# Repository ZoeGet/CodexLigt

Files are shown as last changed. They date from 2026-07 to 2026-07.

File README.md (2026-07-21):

# CodexLight

[English](README.en.md) | 简体中文 | [使用说明](USAGE.md) | [English Usage Guide](USAGE.en.md)

CodexLight 是一套基于 ESP32-C3 的 Codex Desktop 状态灯。Windows 端 Bridge 读取本机 Codex 会话日志，把状态转换为 `GREEN`、`RED`、`YELLOW`，再通过 USB 串口、局域网 UDP 或两者同时发送给 ESP32-C3。固件驱动三颗独立 WS2812B LED 显示空闲、工作和等待状态。

本项目是社区开源项目，与 OpenAI 没有官方关联或背书。

## 当前可用方案

- 配网使用 USB 串口，不再使用 ESP32 AP 热点页面。
- 托盘程序提供 `Configure WiFi`，通过 USB 把 SSID 和密码发送给设备。
- Wi-Fi 只在连接成功后写入 ESP32 NVS；错误密码不会覆盖旧配置。
- 已保存的 Wi-Fi 会在开机后非阻塞连接，并在断线后持续重试。
- ESP32-C3 Wi-Fi 发射功率默认限制为 8.5 dBm，以提升部分开发板的无线连接稳定性。
- 无电脑供电启动不依赖 USB 串口，适合充电宝或电池供电的纯无线摆放。
- 支持 `AUTO`、`WIRED`、`WIRELESS` 三种持久化通信模式。
- `Bridge/start_codex_light_tray.vbs` 默认以无线模式隐藏启动，不保留 PowerShell 窗口。

## 状态定义

| 状态 | Codex 条件 | LED | GPIO |
| --- | --- | --- | --- |
| `GREEN` | 空闲、任务完成或任务中止 | 绿灯 | GPIO6 |
| `RED` | 正在思考、回复、运行工具或处理任务 | 红灯 | GPIO7 |
| `YELLOW` | 等待审批、权限确认或用户输入 | 黄灯 | GPIO5 |
| 未收到电脑心跳 | 6 秒内没有有效 USB/UDP 心跳 | 黄灯慢闪 | GPIO5 |

首次收到有效电脑心跳时，绿灯会闪烁 2 秒作为连接提示，然后显示真实状态。任务完成后的绿色会保持到下一次任务开始、进入等待状态或连接断开。

## 快速开始

1. 安装电脑端依赖：

   ```powershell
   python -m pip install pyserial
   ```

2. 编译并烧录固件：

   ```powershell
   cd Firmware
   pio run
   pio run -t upload --upload-port COM4
   ```

3. 双击启动隐藏托盘，默认进入无线模式：

   ```text
   Bridge\start_codex_light_tray.vbs
   ```

4. 第一次使用时，用 USB 连接 ESP32-C3，右键托盘图标选择 `Configure WiFi`，输入路由器 SSID 和密码。
5. Wi-Fi 保存成功后，可以拔掉电脑 USB，改用充电宝或锂电池供电；托盘会通过 UDP 控灯。

完整流程见 [USAGE.md](USAGE.md)。

## 纯无线使用

1. 先用 USB 完成一次 `Configure WiFi`。
2. 确认托盘模式是 `Wireless only`，或用默认 `start_codex_light_tray.vbs` 启动。
3. 断开电脑 USB，使用充电宝或稳定 5 V 电源给 ESP32-C3 和 LED 供电。
4. 打开托盘后，日志应出现：

   ```text
   SERIAL no matching serial port
   SERIAL setup skipped; using saved firmware mode.
   UDP ack from 192.168.x.x CODEXLIGHT/1 ACK ... active=WIRELESS state=...
   ```

这表示设备未接电脑串口，但已通过 Wi-Fi UDP 正常工作。

## 无串口诊断灯码

| 灯码 | 含义 |
| --- | --- |
| 红黄交替 | 没有读到 Wi-Fi 配置，需要 USB 配网 |
| 红色双闪循环 | 有 Wi-Fi 配置，但正在重连或连接失败 |
| 黄灯慢闪 | Wi-Fi 已连接，正在等待电脑托盘 UDP 心跳 |
| 正常红/绿/黄 | 已收到电脑状态，系统正常工作 |

## 硬件

推荐器件：

- ESP32-C3 SuperMini 或兼容 ESP32-C3 开发板
- 三颗 WS2812B RGB LED
- 稳定 5 V 电源、充电宝或合适的锂电池升压模块
- USB 数据线，用于烧录和第一次 Wi-Fi 配网

接线：

| 功能 | ESP32-C3 引脚 |
| --- | --- |
| 黄灯 DIN | GPIO5 |
| 绿灯 DIN | GPIO6 |
| 红灯 DIN | GPIO7 |
| WS2812B VCC | 5 V |
| WS2812B GND | GND |

三颗 WS2812B 使用三路独立数据输入，不是串联灯带。当前固件使用 `NEO_GRB + NEO_KHZ800`，默认亮度为 `DEFAULT_BRIGHTNESS = 50`，可在 [Firmware/include/config.h](Firmware/include/config.h) 中配置。

## 目录结构

```text
CodexLight/
├── Bridge/        # Windows 日志监听、串口/UDP 发送和托盘程序
├── Firmware/      # ESP32-C3 PlatformIO 固件
├── Hardware/      # BOM、原理图、PCB、Gerber、外壳 STL
├── Docs/          # 使用与实现说明
├── README.md      # 中文项目说明
├── README.en.md   # English project documentation
├── USAGE.md       # 中文使用手册
└── USAGE.en.md    # English usage guide
```

## 验证

```powershell
python -B -m py_compile Bridge\codex_light_monitor.py
powershell -NoProfile -Command "$e=$null; [System.Management.Automation.PSParser]::Tokenize((Get-Content -LiteralPath 'Bridge\CodexLightTray.ps1' -Raw), [ref]$e) | Out-Null; if($e){$e; exit 1}else{'OK'}"
cd Firmware
pio run
```

## 许可

本项目使用 [MIT License](LICENSE)。第三方依赖遵循各自许可。

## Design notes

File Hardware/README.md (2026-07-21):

# CodexLight Hardware

[项目主页](../README.md) | [Project Home](../README.en.md)

本目录包含 CodexLight 的 BOM、原理图、PCB 制造资料和 3D 打印外壳。

This directory contains the CodexLight bill of materials, schematic, PCB manufacturing files, and 3D-printable enclosure.

## Files / 文件

| Path | Description |
| --- | --- |
| `BOM/BOM.xlsx` | 物料清单 / Bill of materials |
| `Schematic/Schematic1.pdf` | 原理图 PDF / Schematic PDF |
| `PCB/Source/CodexLight.epro2` | PCB 源工程 / PCB source project |
| `PCB/Gerber/CodexLight_PCB_Gerber.zip` | Gerber 制造包 / Gerber fabrication package |
| `Enclosure/CodexLight_T.stl` | 上壳 / Top enclosure |
| `Enclosure/CodexLight_B.stl` | 下壳 / Bottom enclosure |

## LED Connections / LED 连接

| LED | GPIO |
| --- | --- |
| Yellow WS2812B DIN / 黄灯 DIN | GPIO5 |
| Green WS2812B DIN / 绿灯 DIN | GPIO6 |
| Red WS2812B DIN / 红灯 DIN | GPIO7 |

三颗 LED 使用独立数据线，不是串联灯带。LED 电源和 ESP32-C3 必须共地，并使用稳定 5 V 供电。

The three LEDs use independent data lines, not a chained strip. The LED supply and ESP32-C3 must share ground, and a stable 5 V supply is required.

## Standalone Power / 独立供电

纯无线使用时，ESP32-C3 和 WS2812B 都需要从充电宝、5 V 稳压模块或锂电池升压模块供电。不要只给 LED 供电；ESP32-C3 的 `5V/VIN` 和 GND 也必须接入同一电源系统。

For wireless-only use, both the ESP32-C3 and WS2812B LEDs must be powered from the power bank, 5 V regulator, or Li-ion boost converter. Do not power only the LEDs. The ESP32-C3 `5V/VIN` and GND must be connected to the same supply system.

## Notes / 注意

- 固件默认使用 `NEO_GRB + NEO_KHZ800`。
- 如果更换不同批次 WS2812B 后颜色不对，请检查色序、DIN 方向、焊接和供电。
- USB 数据线仍然建议保留，因为固件烧录和首次 Wi-Fi 配网依赖 USB 串口。
- ESP32-C3 连接 Wi-Fi 时会有电流尖峰；如果使用小型升压模块，确认动态电压不会跌落。

- Firmware defaults to `NEO_GRB + NEO_KHZ800`.
- If another WS2812B batch displays incorrect colors, verify pixel order, DIN orientation, soldering, and power.
- Keep USB data access available because firmware upload and first-time Wi-Fi provisioning use USB serial.
- ESP32-C3 current spikes during Wi-Fi association. If using a small boost converter, verify dynamic voltage does not sag.

## License

Unless a third-party component states otherwise, hardware files follow the repository [MIT License](../LICENSE).

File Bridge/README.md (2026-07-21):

# CodexLight Bridge

[English](README_en.md) | 简体中文 | [项目主页](../README.md)

Bridge 运行在 Windows 电脑上，读取本机 Codex Desktop 会话日志，把状态映射为 `GREEN`、`RED`、`YELLOW`，再通过 USB 串口、局域网 UDP 或两者同时发送给 ESP32-C3。

## 功能

- 监听 `~/.codex/sessions/**/*.jsonl` 和 `~/.codex/logs_2.sqlite`。
- 支持 USB 串口、UDP、AUTO 混合模式。
- 提供 Windows 托盘菜单：配网、切换模式、查看日志、重启监控、退出。
- 通过 USB 串口为设备配置 Wi-Fi，不使用 ESP32 AP 热点。
- 自动记住最近发现的 UDP 设备，方便下次启动继续使用无线连接。
- 无电脑 USB 时，托盘会跳过串口设置并继续用已保存的无线模式发送 UDP。

## 状态规则

| Codex 事件 | 输出 |
| --- | --- |
| `task_started`、推理、消息、工具调用和工具输出 | `RED` |
| 工具调用需要审批、权限或用户输入 | `YELLOW` |
| `task_complete` 或 `turn_aborted` | `GREEN` |

Bridge 只发送颜色状态，不发送 Codex 消息正文、工具输出、API Key 或登录令牌。

## 依赖

```powershell
python -m pip install pyserial
```

## 托盘启动

推荐双击隐藏启动器，默认进入 `WIRELESS` 模式：

```text
Bridge\start_codex_light_tray.vbs
```

旧批处理也可用，但可能短暂显示控制台窗口：

```text
Bridge\start_codex_light_tray.bat
```

托盘菜单：

- `Configure WiFi`：通过 USB 写入路由器 SSID/密码。
- `Connection mode`：切换 `Auto (wired + wireless)`、`Wired only`、`Wireless only`。
- `Open log folder`：打开 `Bridge/logs`。
- `Restart monitor`：重启监控进程。
- `Exit`：退出。

## Wi-Fi 配网

托盘 `Configure WiFi` 会暂停监控进程，打开串口，发送：

```text
WIFI_SET <ssid><TAB><password>
```

设备连接成功后返回：

```text
WIFI_SET_OK <ssid> <ip>
```

失败日志保存到：

```text
Bridge\logs\wifi_setup.out.log
Bridge\logs\wifi_setup.err.log
```

命令行配网：

```powershell
python Bridge\codex_light_monitor.py --serial auto --wifi-ssid "YourWifi" --wifi-password "YourPassword"
```

## 运行模式

| 模式 | Bridge 行为 |
| --- | --- |
| `WIRED` | 打开串口并只通过 USB 发送状态 |
| `WIRELESS` | 通过 UDP 发送状态；如果 USB 存在，会用串口保存 `MODE WIRELESS` 后释放；如果 USB 不存在，会直接使用设备已保存模式 |
| `AUTO` | 串口和 UDP 同时启用，固件优先使用新鲜串口心跳 |

手动运行：

```powershell
python Bridge\codex_light_monitor.py --serial auto --baud 115200
python Bridge\codex_light_monitor.py --udp --udp-port 4210
python Bridge\codex_light_monitor.py --serial auto --baud 115200 --udp --udp-port 4210 --firmware-mode AUTO
```

## 常用参数

| 参数 | 说明 |
| --- | --- |
| `--serial COM4` | 指定串口 |
| `--serial auto` | 自动选择常见 ESP32/USB 串口 |
| `--baud 115200` | 串口波特率 |
| `--udp` | 启用 UDP 状态发送和发现 |
| `--udp-port 4210` | UDP 端口 |
| `--firmware-mode AUTO` | 通过串口保存固件模式 |
| `--serial-setup-only` | 串口只用于模式设置，确认后释放 |
| `--reset-on-connect` | 打开串口后发送 ESP32 reset pulse，用于无线托盘启动时初始化设备 |
| `--wifi-ssid` / `--wifi-password` | 一次性 USB Wi-Fi 配网 |
| `--wifi-config path.json` | 从 JSON 文件读取 `{ "ssid": "...", "password": "..." }` |

## 日志

- `Bridge/logs/codex_light_monitor.out.log`
- `Bridge/logs/codex_light_monitor.err.log`
- `Bridge/logs/wifi_setup.out.log`
- `Bridge/logs/wifi_setup.err.log`

## 验证

```powershell
python -B -m py_compile Bridge\codex_light_monitor.py
powershell -NoProfile -Command "$e=$null; [System.Management.Automation.PSParser]::Tokenize((Get-Content -LiteralPath 'Bridge\CodexLightTray.ps1' -Raw), [ref]$e) | Out-Null; if($e){$e; exit 1}else{'OK'}"
```

## License

Bridge 遵循仓库根目录的 [MIT License](../LICENSE)。

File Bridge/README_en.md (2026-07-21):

# CodexLight Bridge

English | [简体中文](README.md) | [Project Home](../README.en.md)

The Bridge runs on the Windows computer hosting Codex Desktop. It reads local Codex session logs, maps activity to `GREEN`, `RED`, or `YELLOW`, and sends the state to the ESP32-C3 over USB serial, LAN UDP, or both.

## Features

- Monitors `~/.codex/sessions/**/*.jsonl` and `~/.codex/logs_2.sqlite`.
- Supports USB serial, UDP, and mixed AUTO mode.
- Provides a Windows tray menu for Wi-Fi setup, mode switching, logs, monitor restart, and exit.
- Configures device Wi-Fi over USB serial. The firmware no longer uses an ESP32 AP portal.
- Remembers the most recently discovered UDP device for wireless startup.
- When no computer USB is connected, the tray skips serial setup and continues UDP using the device's saved wireless mode.

## State Rules

| Codex event | Output |
| --- | --- |
| `task_started`, reasoning, messages, tool calls, and tool outputs | `RED` |
| A tool call requires approval, permission, or user input | `YELLOW` |
| `task_complete` or `turn_aborted` | `GREEN` |

The Bridge sends only color states. It never sends Codex message text, tool output, API keys, or login tokens to the device.

## Dependency

```powershell
python -m pip install pyserial
```

## Tray Startup

Recommended hidden launcher. It defaults to `WIRELESS` mode:

```text
Bridge\start_codex_light_tray.vbs
```

The legacy batch launcher is also available, but it may briefly show a console window:

```text
Bridge\start_codex_light_tray.bat
```

Tray menu:

- `Configure WiFi`: write router SSID/password over USB.
- `Connection mode`: switch between `Auto (wired + wireless)`, `Wired only`, and `Wireless only`.
- `Open log folder`: open `Bridge/logs`.
- `Restart monitor`: restart the monitor process.
- `Exit`: quit.

## Wi-Fi Provisioning

The tray `Configure WiFi` action pauses the monitor process, opens serial, and sends:

```text
WIFI_SET <ssid><TAB><password>
```

On success, the device replies:

```text
WIFI_SET_OK <ssid> <ip>
```

Failure logs are written to:

```text
Bridge\logs\wifi_setup.out.log
Bridge\logs\wifi_setup.err.log
```

Command-line provisioning:

```powershell
python Bridge\codex_light_monitor.py --serial auto --wifi-ssid "YourWifi" --wifi-password "YourPassword"
```

## Run Modes

| Mode | Bridge behavior |
| --- | --- |
| `WIRED` | Opens serial and sends states only over USB |
| `WIRELESS` | Sends states over UDP; if USB exists, serial saves `MODE WIRELESS` and is released; if USB is absent, the saved firmware mode is used |
| `AUTO` | Enables serial and UDP; firmware prefers a fresh serial heartbeat |

Manual commands:

```powershell
python Bridge\codex_light_monitor.py --serial auto --baud 115200
python Bridge\codex_light_monitor.py --udp --udp-port 4210
python Bridge\codex_light_monitor.py --serial auto --baud 115200 --udp --udp-port 4210 --firmware-mode AUTO
```

## Common Options

| Option | Description |
| --- | --- |
| `--serial COM4` | Use a specific serial port |
| `--serial auto` | Auto-select a common ESP32/USB serial device |
| `--baud 115200` | Serial baud rate |
| `--udp` | Enable UDP state output and discovery |
| `--udp-port 4210` | UDP port |
| `--firmware-mode AUTO` | Persist firmware mode over serial |
| `--serial-setup-only` | Use serial only for mode setup, then release it |
| `--reset-on-connect` | Pulse ESP32 reset lines after opening serial; used by wireless tray startup to initialize the device |
| `--wifi-ssid` / `--wifi-password` | One-shot USB Wi-Fi provisioning |
| `--wifi-config path.json` | Read `{ "ssid": "...", "password": "..." }` from JSON |

## Logs

- `Bridge/logs/codex_light_monitor.out.log`
- `Bridge/logs/codex_light_monitor.err.log`
- `Bridge/logs/wifi_setup.out.log`
- `Bridge/logs/wifi_setup.err.log`

## Verification

```powershell
python -B -m py_compile Bridge\codex_light_monitor.py
powershell -NoProfile -Command "$e=$null; [System.Management.Automation.PSParser]::Tokenize((Get-Content -LiteralPath 'Bridge\CodexLightTray.ps1' -Raw), [ref]$e) | Out-Null; if($e){$e; exit 1}else{'OK'}"
```

## License

The Bridge is covered by the repository's [MIT License](../LICENSE).

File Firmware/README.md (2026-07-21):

# CodexLight Firmware

[项目主页](../README.md) | [Project Home](../README.en.md)

本目录是 ESP32-C3 端 PlatformIO Arduino 固件。固件负责 USB Wi-Fi 配网、STA 联网、USB 串口/UDP 心跳接收、通信模式持久化、无串口启动诊断灯码和三路 WS2812B 状态显示。

This directory contains the ESP32-C3 PlatformIO Arduino firmware. It handles USB Wi-Fi provisioning, STA networking, USB serial/UDP heartbeats, persistent transport modes, standalone LED diagnostics, and three independent WS2812B status LEDs.

## Build Environment / 构建环境

```ini
platform = espressif32@6.6.0
board = esp32-c3-devkitm-1
framework = arduino
monitor_speed = 115200
```

PlatformIO installs the external dependency automatically:

- `Adafruit NeoPixel`

当前固件不再依赖 `WiFiManager`、`ESPAsyncWebServer` 或 AP 配网页面。

The current firmware no longer depends on `WiFiManager`, `ESPAsyncWebServer`, or an AP provisioning portal.

## Build and Upload / 编译与烧录

```powershell
cd Firmware
pio run
pio run -t upload --upload-port COM4
pio device monitor --port COM4 --baud 115200
```

普通串口监视器会占用 COM 口。使用 Bridge 或托盘前请关闭 PlatformIO Monitor。

Close PlatformIO Monitor before starting the Bridge or tray because only one process can use the COM port.

## Main Configuration / 主要配置

Edit `include/config.h`:

| Setting | Default | Description |
| --- | --- | --- |
| `YELLOW_LED_PIN` | `5` | Yellow LED data pin |
| `GREEN_LED_PIN` | `6` | Green LED data pin |
| `RED_LED_PIN` | `7` | Red LED data pin |
| `DEFAULT_BRIGHTNESS` | `50` | NeoPixel brightness |
| `SERIAL_BAUD` | `115200` | USB CDC baud rate |
| `UDP_PORT` | `4210` | UDP listen/discovery port |
| `LINK_TIMEOUT_MS` | `6000` | Desktop heartbeat timeout |
| `WIFI_CONNECT_TIMEOUT_MS` | `15000` | Blocking connect timeout used only during USB provisioning validation |
| `WIFI_RECONNECT_INTERVAL_MS` | `10000` | Non-blocking saved Wi-Fi retry interval |
| `WIFI_MAX_TX_POWER_QDBM` | `34` | ESP-IDF quarter-dBm units; 34 means 8.5 dBm |
| `DEFAULT_TRANSPORT_MODE` | `AUTO` | Default mode when NVS has none |
| `DEBUG_SERIAL` | `false` | Default debug logging; keep disabled for standalone wireless operation |

`CONFIG_AP_*` constants are retained only for compatibility. The main firmware does not start a SoftAP.

`CONFIG_AP_*` 常量仅保留兼容用途，主固件不会启动热点。

## Wi-Fi Provisioning / Wi-Fi 配网

Use USB serial:

```text
WIFI_SET <ssid><TAB><password>
```

During provisioning, the firmware validates the credentials by attempting STA connection. Credentials are saved in Preferences namespace `wifi` only after successful connection:

```text
ssid
password
```

配网失败不会覆盖旧配置。保存过 Wi-Fi 后，启动时使用非阻塞连接；如果连接失败，固件保留凭据并按 `WIFI_RECONNECT_INTERVAL_MS` 持续重试。

Failed provisioning does not overwrite existing credentials. Once Wi-Fi is saved, boot uses a non-blocking connect path. If the connection fails, credentials are kept and the firmware retries every `WIFI_RECONNECT_INTERVAL_MS`.

Clear Wi-Fi:

```text
CLEAR_WIFI
```

## Transport Modes / 通信模式

| Mode | Behavior |
| --- | --- |
| `WIRED` | Accept USB serial heartbeat only |
| `WIRELESS` | Accept UDP heartbeat only |
| `AUTO` | Accept both; fresh USB heartbeat has priority |

Commands:

```text
MODE WIRED
MODE WIRELESS
MODE AUTO
STATUS
```

The selected mode is saved in Preferences namespace `codexlight`, key `transport`.

## LED Runtime and Diagnostics / LED 运行与诊断

| Pattern | Meaning |
| --- | --- |
| Solid green | Idle, task complete, or task aborted |
| Solid red | Codex is working |
| Solid yellow | Waiting for approval, permission, or user input |
| Green blink for 2 seconds | First desktop heartbeat connected |
| Slow yellow blink | Wi-Fi is connected but no desktop heartbeat has arrived |
| Alternating red/yellow | No saved Wi-Fi credentials |
| Repeating red double-blink | Saved Wi-Fi exists but reconnect is in progress or failed |

独立供电时不要依赖串口输出判断状态，直接看灯码即可。

When running from a power bank or battery, use the LED diagnostics instead of serial output.

## Serial Commands / 串口命令

```text
GREEN
RED
YELLOW
PING
STATUS
MODE WIRED
MODE WIRELESS
MODE AUTO
WIFI_CONFIG
WIFI_SET <ssid><TAB><password>
CLEAR_WIFI
LED_TEST RED
LED_TEST GREEN
LED_TEST YELLOW
LED_TEST OFF
```

`WIFI_CONFIG` only prints the USB provisioning hint. It does not open an AP.

`WIFI_CONFIG` 只提示使用 USB 配网，不会打开热点。

## UDP Protocol / UDP 协议

Accepted packets:

```text
CODEXLIGHT/1 GREEN
CODEXLIGHT/1 RED
CODEXLIGHT/1 YELLOW
CODEXLIGHT/1 PING
```

Acknowledgement:

```text
CODEXLIGHT/1 ACK mac=<MAC> mode=<MODE> active=<TRANSPORT> state=<STATE>
```

Discovery:

```text
CODEXLIGHT/1 HELLO mac=<MAC> mode=<MODE>
```

## Files / 文件

- `src/main.cpp`: serial commands, UDP heartbeat, transport selection, LED state machine, diagnostics.
- `src/config_portal.cpp`: STA Wi-Fi, USB provisioning wrapper, non-blocking saved Wi-Fi reconnect.
- `src/storage.cpp`: Preferences read/write for Wi-Fi credentials.
- `src/led.cpp`: three independent Adafruit NeoPixel outputs.
- `include/config.h`: user-editable GPIO, timing, brightness, port, and Wi-Fi power settings.
- `platformio.ini`: PlatformIO environment and dependencies.

## NVS and Reset / NVS 与擦除

Wi-Fi credentials and transport mode are stored in NVS. Normal firmware upload does not erase them.

```powershell
pio run -t erase --upload-port COM4
pio run -t upload --upload-port COM4
```

Usually `CLEAR_WIFI` and `MODE ...` are enough. Full erase is only needed for factory reset or corrupted NVS.

## License

Firmware follows the repository [MIT License](../LICENSE). Third-party dependencies keep their own licenses.

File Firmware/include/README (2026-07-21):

# Firmware Headers

Project header files / 项目头文件：

- `config.h`: GPIO assignments, brightness, serial baud, UDP port, timeouts, default transport mode, standalone diagnostic behavior, and ESP32-C3 Wi-Fi transmit power.
- `config_portal.h`: STA Wi-Fi connection and USB provisioning wrapper. The name is kept for compatibility with older code; AP provisioning is no longer used.
- `storage.h`: Preferences storage for Wi-Fi SSID/password.
- `led.h`: three-channel LED controller interface.

用户通常只需要修改 `config.h`。修改后重新运行 `pio run` 并烧录。

Users normally edit `config.h` only. Rebuild and upload after changing it.

See `Firmware/README.md` and the repository root README for complete instructions.

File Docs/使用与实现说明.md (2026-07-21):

# CodexLight 使用与实现说明

[English](USAGE_AND_IMPLEMENTATION.md) | 简体中文 | [返回文档索引](README.md) | [项目主页](../README.md)

本文合并项目操作手册和技术实现说明，覆盖固件烧录、USB Wi-Fi 配网、有线/无线运行、排障和维护。

## 硬件连接

| LED | 数据引脚 | 状态 |
| --- | --- | --- |
| 黄色 WS2812B | GPIO5 | 未连接、等待或诊断 |
| 绿色 WS2812B | GPIO6 | 连接动画或任务完成 |
| 红色 WS2812B | GPIO7 | Codex 正在工作或 Wi-Fi 重连诊断 |

三颗 WS2812B 分别使用独立 DIN。VCC 接稳定 5 V，GND 与 ESP32-C3 共地。

## 编译与烧录

```powershell
cd C:\path\to\CodexLight\Firmware
pio run
pio run -t upload --upload-port COM4
pio device monitor --port COM4 --baud 115200
```

启动 Bridge 前请关闭 PlatformIO Monitor，因为它们会占用同一个串口。

## USB Wi-Fi 配网

当前固件不会开启 SoftAP 配网页面。配网通过 USB 串口完成。

托盘流程：

1. USB 连接设备。
2. 启动 `Bridge\start_codex_light_tray.vbs`，该启动器默认进入 `WIRELESS` 模式。
3. 右键托盘图标，选择 `Configure WiFi`。
4. 输入 SSID/密码并保存。

命令行流程：

```powershell
python Bridge\codex_light_monitor.py --serial auto --wifi-ssid "YourWifi" --wifi-password "YourPassword"
```

固件命令：

```text
WIFI_SET <ssid><TAB><password>
```

只有当 `WiFi.status() == WL_CONNECTED` 时，固件才保存 Wi-Fi。失败尝试不会写入 Flash。

## 通信模式

| 模式 | 行为 |
| --- | --- |
| `WIRED` | 只接收 USB 串口心跳 |
| `WIRELESS` | 只接收 UDP 心跳 |
| `AUTO` | 同时接收 USB 和 UDP；USB 心跳新鲜时优先 |

模式命令：

```text
MODE WIRED
MODE WIRELESS
MODE AUTO
STATUS
```

模式保存在 Preferences namespace `codexlight` 的 `transport` 键中。

## Windows 托盘

使用隐藏启动器，默认进入 `WIRELESS` 模式：

```text
Bridge\start_codex_light_tray.vbs
```

托盘提供：

- `Configure WiFi`：USB 配网。
- `Connection mode`：切换 AUTO、WIRED、WIRELESS。
- `Open log folder`：打开 `Bridge/logs`。
- `Restart monitor`：重启 `codex_light_monitor.py`。
- `Exit`：退出托盘。

无线托盘路径在 USB 存在时只短暂打开串口，发送 reset pulse 和 `MODE WIRELESS` 后释放端口。没有 USB 串口时，它会记录 `SERIAL setup skipped; using saved firmware mode.`，然后继续通过 UDP 发送状态。

## 总体架构

```text
Codex Desktop logs
        |
        v
Bridge/codex_light_monitor.py
        |
        +-- USB CDC serial: GREEN / RED / YELLOW / MODE / WIFI_SET
        +-- LAN UDP: CODEXLIGHT/1 <STATE> and CODEXLIGHT/1 PING
                         |
                         v
                  ESP32-C3 firmware
                         |
                         +-- Preferences: wifi ssid/password, transport mode
                         +-- non-blocking saved Wi-Fi reconnect
                         +-- GPIO5 yellow WS2812B
                         +-- GPIO6 green WS2812B
                         +-- GPIO7 red WS2812B
```

## Bridge 实现

Bridge 读取：

- `~/.codex/sessions/**/*.jsonl`
- `~/.codex/logs_2.sqlite`

它只向设备发送颜色状态。

| Codex 事件 | 输出 |
| --- | --- |
| `task_started`、消息、推理、工具调用、工具输出 | `RED` |
| 需要审批、权限或用户输入 | `YELLOW` |
| `task_complete` 或 `turn_aborted` | `GREEN` |

托盘配网会暂停监控，运行一次性 `--wifi-config` 子进程，把日志写到 `Bridge/logs/wifi_setup.*.log`，然后恢复监控。

## 固件实现

主要文件：

- `Firmware/src/main.cpp`：串口命令解析、UDP 心跳、传输选择、LED 状态机、诊断灯码。
- `Firmware/src/config_portal.cpp`：STA Wi-Fi 连接、USB 配网封装、已保存 Wi-Fi 的非阻塞重连。
- `Firmware/src/storage.cpp`：Wi-Fi 凭据 Preferences 存储。
- `Firmware/src/led.cpp`：三路独立 NeoPixel 输出。
- `Firmware/include/config.h`：GPIO、亮度、超时、UDP 端口、默认模式和 ESP32-C3 Wi-Fi 发射功率。

Wi-Fi 说明：

- 固件只使用 USB 串口配网。
- 只有 STA 到达 `WL_CONNECTED` 后才保存凭据。
- 已保存 Wi-Fi 在启动时非阻塞连接，即使路由器不可达，LED 诊断和主循环也会继续运行。
- 已保存 Wi-Fi 失败时保留凭据，并每 10 秒重试。
- ESP32-C3 发射功率限制为 `WIFI_MAX_TX_POWER_QDBM = 34`，即 8.5 dBm，以提升小型开发板的无线稳定性。
- 默认关闭调试串口输出，便于独立供电无线运行。

启动流程：

```text
setup
  -> 初始化 LED 并显示启动黄灯
  -> 读取已保存 Wi-Fi 凭据
  -> 如果存在，非阻塞启动 STA 连接
  -> 读取已保存通信模式
loop
  -> 需要时继续尝试 Wi-Fi 重连
  -> 处理可用 USB 串口命令
  -> Wi-Fi 已连接时维护 UDP
  -> 选择活动传输
  -> 渲染 LED 状态或无串口诊断灯码
```

## 协议

串口命令：

```text
GREEN
RED
YELLOW
PING
STATUS
MODE WIRED
MODE WIRELESS
MODE AUTO
WIFI_CONFIG
WIFI_SET <ssid><TAB><password>
CLEAR_WIFI
LED_TEST RED
LED_TEST GREEN
LED_TEST YELLOW
LED_TEST OFF
```

UDP 状态、PING、ACK 和发现：

```text
CODEXLIGHT/1 GREEN
CODEXLIGHT/1 RED
CODEXLIGHT/1 YELLOW
CODEXLIGHT/1 PING
CODEXLIGHT/1 ACK mac=<MAC> mode=<MODE> active=<TRANSPORT> state=<STATE>
CODEXLIGHT/1 HELLO mac=<MAC> mode=<MODE>
```

## 常见问题

- Wi-Fi 配网失败：查看 `Bridge/logs/wifi_setup.out.log` 和 `.err.log`，关闭 PlatformIO Monitor，确认使用 2.4 GHz Wi-Fi，并确认固件使用 `WIFI_MAX_TX_POWER_QDBM = 34`。
- 无线不更新：确认同一局域网、防火墙允许 UDP 4210，并重启托盘重新发现设备。
- 黄灯慢闪：Wi-Fi 已连接，固件正在等待电脑心跳；打开托盘。
- 红色双闪：有保存的 Wi-Fi，但连接失败或正在重连。
- 颜色错误：确认 `NEO_GRB`、DIN 方向、GPIO 连通性和 5 V 供电。

## 安全

- Wi-Fi 凭据保存在 ESP32 NVS，固件不会通过串口打印密码。
- UDP 未加密也未鉴权，只应在可信局域网使用。

## 验证

```powershell
python -B -m py_compile Bridge\codex_light_monitor.py
cd Firmware
pio run
```

## 许可

项目遵循仓库根目录的 [MIT License](../LICENSE)。

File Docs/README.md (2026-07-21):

# CodexLight Documentation

[项目主页](../README.md) | [Project Home](../README.en.md)

本目录保存面向用户和维护者的补充文档。

This directory contains supplemental documentation for users and maintainers.

| Document | Purpose |
| --- | --- |
| [中文使用说明](../USAGE.md) | 根目录中文操作手册 / Root Chinese operating guide |
| [English Usage Guide](../USAGE.en.md) | Root English operating guide / 根目录英文操作手册 |
| [使用与实现说明](使用与实现说明.md) | 中文操作、架构和维护说明 / Chinese usage, architecture, and maintenance guide |
| [Usage and Implementation Guide](USAGE_AND_IMPLEMENTATION.md) | English usage, architecture, and maintenance guide / 英文操作、架构和维护说明 |

根目录 README 和 USAGE 是主要用户入口。修改协议、配网、连接模式、GPIO、启动方式、纯无线供电或排障流程时，请同步更新中英文文档。

The root README and USAGE files are the primary user-facing source of truth. Update both languages whenever protocol, provisioning, transport modes, GPIOs, startup behavior, standalone power, or troubleshooting steps change.

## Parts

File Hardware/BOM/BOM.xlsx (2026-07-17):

序号 | 原始需求 | 原始需求 | 原始需求 | 原始需求
序号 | 型号 | 封装 | 单套用量 | 位号
1 | 1K | R0603 | 1 | R1
2 | 100nF | C0603 | 3 | C3,C4,C5
3 | 330 | R0603 | 3 | R2,R3,R4
4 | 22uF | C0603 | 1 | C2
5 | WS2812B-YELLOW | 5050 | 1 | YELLOW
6 | WS2812B-RED | 5050 | 1 | RED
7 | 10uF | C0603 | 1 | C1
8 | LED_0603-R | LED_0603 | 2 | LED4,LED5
9 | ETA6093S2F | SOT-23-5 | 1 | U1
10 | 2.2uH | L1008 | 1 | L1
11 | 1x8P | L8.5MM H5.0MM | 2 | RIGHT,LIFT
12 | WS2812B-GREEN | 5050 | 1 | GREEN
13 | MX1.25 BAT | MX1.25 Battery-601015 | 1 | BAT1
14 | M3螺丝 | M3x20 | 2

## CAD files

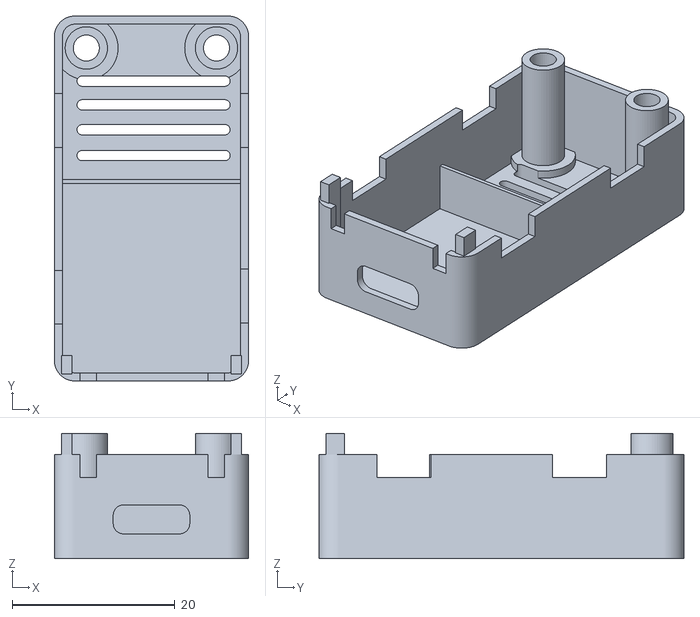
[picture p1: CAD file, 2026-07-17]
Hardware/Enclosure/CodexLight_B.stl
23.9 x 44.8 x 15.4

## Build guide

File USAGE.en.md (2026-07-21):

# CodexLight Usage Guide

English | [简体中文](USAGE.md) | [Project Home](README.en.md)

This guide covers firmware upload, USB Wi-Fi provisioning, wired/wireless/AUTO modes, Windows tray operation, serial commands, UDP protocol, standalone power, troubleshooting, and verification.

## Prerequisites

Desktop requirements:

- Windows 10/11
- Python 3.9+
- Codex Desktop
- `pyserial`

```powershell
python -m pip install pyserial
```

Firmware development requires PlatformIO Core or the VS Code PlatformIO IDE. PlatformIO installs `Adafruit NeoPixel` automatically.

## Build and Upload

```powershell
cd C:\path\to\CodexLight\Firmware
pio run
pio run -t upload --upload-port COM4
```

Replace `COM4` with the actual ESP32-C3 port. Open the serial monitor with:

```powershell
pio device monitor --port COM4 --baud 115200
```

PlatformIO Monitor, serial terminal apps, and the Bridge cannot use the same COM port at the same time. Close the monitor before starting the tray.

## USB Wi-Fi Provisioning

The current firmware no longer opens an ESP32 AP portal. Use the tray:

1. Connect CodexLight to the computer over USB.
2. Start the tray by double-clicking `Bridge\start_codex_light_tray.vbs`. This launcher defaults to `WIRELESS` mode.
3. Right-click the tray icon and choose `Configure WiFi`.
4. Enter the 2.4 GHz router SSID and password.
5. Click `Save`.

On success, the tray shows `WiFi saved and connected.` The device saves credentials only after a successful connection. Wrong passwords, missing SSIDs, or timeouts do not overwrite the previous saved configuration.

Command-line provisioning is also available:

```powershell
python Bridge\codex_light_monitor.py --serial auto --wifi-ssid "YourWifi" --wifi-password "YourPassword"
```

Successful output:

```text
DEVICE WIFI_SET_OK YourWifi 192.168.x.x
```

Failure logs:

```text
Bridge\logs\wifi_setup.out.log
Bridge\logs\wifi_setup.err.log
```

## Windows Tray

Recommended launcher:

```text
Bridge\start_codex_light_tray.vbs
```

This starts the tray without leaving a PowerShell window open and defaults to `WIRELESS` mode. To exit, right-click the tray icon and choose `Exit`.

The legacy batch launcher is still available:

```text
Bridge\start_codex_light_tray.bat
```

Startup mode can be selected explicitly:

```powershell
Bridge\start_codex_light_tray.bat auto
Bridge\start_codex_light_tray.bat wired
Bridge\start_codex_light_tray.bat wireless
```

Tray menu:

- `Configure WiFi`: configure Wi-Fi over USB.
- `Connection mode`: switch between `Auto`, `Wired only`, and `Wireless only`.
- `Open log folder`: open Bridge logs.
- `Restart monitor`: restart the Bridge monitor process.
- `Exit`: quit the tray app.

## Wired, Wireless, and AUTO Modes

| Mode | Behavior | Recommended use |
| --- | --- | --- |
| `AUTO` | Bridge sends over USB and UDP; firmware prefers a fresh USB heartbeat and can fall back to UDP after USB expires | Daily debugging or mixed connection |
| `WIRED` | USB serial only | Firmware validation, serial debugging, unstable Wi-Fi |
| `WIRELESS` | Wi-Fi UDP only; USB is used only for provisioning or mode setup | Cable-free placement |

The selected mode is stored in ESP32 NVS and survives normal firmware uploads.

## Wireless-Only Workflow

1. Plug into the computer over USB and complete `Configure WiFi` once.
2. From the tray, choose `Connection mode` -> `Wireless only`.
3. Quit the tray.
4. Unplug the computer USB and power the device from a power bank or stable battery-powered 5 V supply.
5. Wait 20 to 60 seconds and check the LED pattern.
6. Start the tray.
7. If the log shows `UDP ack ... active=WIRELESS state=...`, wireless mode is working.

When there is no computer USB connection, these log lines are expected:

```text
SERIAL no matching serial port
SERIAL setup skipped; using saved firmware mode.
```

## LED Behavior and Diagnostics

| LED pattern | Meaning |
| --- | --- |
| Solid green | Idle, task complete, or task aborted |
| Solid red | Codex is reasoning, responding, or running tools |
| Solid yellow | Waiting for approval, permission, or user input |
| Green blink for 2 seconds | First desktop connection established |
| Slow yellow blink | Wi-Fi is connected, but no desktop USB/UDP heartbeat has arrived |
| Alternating red/yellow | No saved Wi-Fi credentials; provision over USB |
| Repeating red double-blink | Saved Wi-Fi exists, but Wi-Fi is reconnecting or failed |

## Manual Bridge Commands

Wired:

```powershell
python Bridge\codex_light_monitor.py --serial auto --baud 115200
```

Wireless:

```powershell
python Bridge\codex_light_monitor.py --udp --udp-port 4210
```

AUTO:

```powershell
python Bridge\codex_light_monitor.py --serial auto --baud 115200 --udp --udp-port 4210 --firmware-mode AUTO
```

Wireless mode requires the computer and ESP32 to be on the same LAN, with router AP/client isolation disabled. Windows Firewall must allow Python to use UDP port `4210`.

## Serial Commands

| Command | Effect |
| --- | --- |
| `GREEN` | Set wired state to green and refresh heartbeat |
| `RED` | Set wired state to red and refresh heartbeat |
| `YELLOW` | Set wired state to yellow and refresh heartbeat |
| `PING` | Refresh wired heartbeat and reply with `PONG` |
| `STATUS` | Print mode, active transport, Wi-Fi, IP, and UDP diagnostics |
| `MODE WIRED` | Use USB only and persist mode |
| `MODE WIRELESS` | Use UDP only and persist mode |
| `MODE AUTO` | Accept USB and UDP and persist mode |
| `WIFI_CONFIG` | Print the USB provisioning hint |
| `WIFI_SET <ssid><TAB><password>` | Configure Wi-Fi over USB; save only after connection succeeds |
| `CLEAR_WIFI` | Clear saved Wi-Fi and wait for provisioning |

## UDP Protocol

Bridge sends:

```text
CODEXLIGHT/1 GREEN
CODEXLIGHT/1 RED
CODEXLIGHT/1 YELLOW
CODEXLIGHT/1 PING
```

ESP32 replies:

```text
CODEXLIGHT/1 ACK mac=<MAC> mode=<MODE> active=<TRANSPORT> state=<STATE>
```

ESP32 also broadcasts discovery:

```text
CODEXLIGHT/1 HELLO mac=<MAC> mode=<MODE>
```

The default UDP port is `4210`.

## Troubleshooting

### Wi-Fi setup fails

- Confirm USB is connected and PlatformIO Monitor or another serial terminal is not using the COM port.
- ESP32-C3 supports 2.4 GHz Wi-Fi only.
- Check `Bridge/logs/wifi_setup.out.log` and `Bridge/logs/wifi_setup.err.log`.
- The current firmware defaults ESP32-C3 Wi-Fi transmit power to 8.5 dBm to improve connection stability on some development boards.

### Wireless mode does not respond

- Slow yellow blink means Wi-Fi is connected and the device is waiting for tray UDP; start the tray.
- Repeating red double-blink means Wi-Fi is reconnecting or failed; check router, SSID/password, and 2.4 GHz availability.
- If `ping 192.168.x.x` fails and `arp -a` does not show the device MAC, the device is not online on the LAN.
- Restart the tray to force device rediscovery.
- Allow Python through Windows Firewall for UDP `4210`.

### Full factory reset

```powershell
cd Firmware
pio run -t erase --upload-port COM4
pio run -t upload --upload-port COM4
```

## Development Verification

```powershell
python -B -m py_compile Bridge\codex_light_monitor.py
powershell -NoProfile -Command "$e=$null; [System.Management.Automation.PSParser]::Tokenize((Get-Content -LiteralPath 'Bridge\CodexLightTray.ps1' -Raw), [ref]$e) | Out-Null; if($e){$e; exit 1}else{'OK'}"
cd Firmware
pio run
```

For architecture details, see [Docs/USAGE_AND_IMPLEMENTATION.md](Docs/USAGE_AND_IMPLEMENTATION.md).

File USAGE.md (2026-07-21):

# CodexLight 使用说明

[English](USAGE.en.md) | 简体中文 | [返回项目主页](README.md)

本文说明 CodexLight 的固件烧录、USB Wi-Fi 配网、有线/无线/AUTO 模式、Windows 托盘、串口命令、UDP 协议、纯无线供电和排障流程。

## 准备

电脑端需要：

- Windows 10/11
- Python 3.9+
- Codex Desktop
- `pyserial`

```powershell
python -m pip install pyserial
```

固件端需要 PlatformIO Core 或 VS Code PlatformIO IDE。PlatformIO 会自动安装 `Adafruit NeoPixel`。

## 编译和烧录

```powershell
cd C:\path\to\CodexLight\Firmware
pio run
pio run -t upload --upload-port COM4
```

把 `COM4` 换成实际 ESP32-C3 端口。查看串口输出：

```powershell
pio device monitor --port COM4 --baud 115200
```

PlatformIO Monitor、其他串口程序和 Bridge 不能同时占用同一个 COM 口。使用托盘前先关闭串口监视器。

## USB Wi-Fi 配网

当前固件不再开启 ESP32 热点配网，推荐使用托盘：

1. 用 USB 数据线连接电脑和 CodexLight。
2. 双击 `Bridge\start_codex_light_tray.vbs` 启动托盘。默认是 `WIRELESS` 模式。
3. 右键托盘图标，选择 `Configure WiFi`。
4. 输入 2.4 GHz 路由器 SSID 和密码。
5. 点击 `Save`。

成功后会显示 `WiFi saved and connected.`。设备只会在连接成功后保存 Wi-Fi；密码错误、SSID 不存在或连接超时不会覆盖旧配置。

命令行配网：

```powershell
python Bridge\codex_light_monitor.py --serial auto --wifi-ssid "YourWifi" --wifi-password "YourPassword"
```

成功输出类似：

```text
DEVICE WIFI_SET_OK YourWifi 192.168.x.x
```

失败日志：

```text
Bridge\logs\wifi_setup.out.log
Bridge\logs\wifi_setup.err.log
```

## Windows 托盘

推荐启动方式：

```text
Bridge\start_codex_light_tray.vbs
```

这个启动器会隐藏 PowerShell 窗口，并默认进入 `WIRELESS` 模式。退出时请右键托盘图标选择 `Exit`。

旧批处理启动器仍可用：

```text
Bridge\start_codex_light_tray.bat
```

可指定模式：

```powershell
Bridge\start_codex_light_tray.bat auto
Bridge\start_codex_light_tray.bat wired
Bridge\start_codex_light_tray.bat wireless
```

托盘菜单：

- `Configure WiFi`：通过 USB 配网。
- `Connection mode`：切换 `Auto`、`Wired only`、`Wireless only`。
- `Open log folder`：打开日志目录。
- `Restart monitor`：重启 Bridge 监控进程。
- `Exit`：退出托盘程序。

## 有线、无线和 AUTO 模式

| 模式 | 行为 | 使用建议 |
| --- | --- | --- |
| `AUTO` | Bridge 同时发 USB 和 UDP；固件优先使用 6 秒内新鲜的 USB 心跳，USB 断开后可切到 UDP | 日常调试或混合连接 |
| `WIRED` | 只使用 USB 串口 | 烧录后验证、串口调试、Wi-Fi 不稳定时 |
| `WIRELESS` | 只使用 Wi-Fi UDP；USB 只用于配网或保存模式后释放 | 设备脱离电脑摆放时推荐 |

模式会保存到 ESP32 NVS，普通固件上传不会清除。

## 纯无线使用流程

1. 插电脑 USB，使用 `Configure WiFi` 成功保存 Wi-Fi。
2. 右键托盘，选择 `Connection mode` -> `Wireless only`。
3. 关闭托盘。
4. 断开电脑 USB，使用充电宝或锂电池升压 5 V 供电。
5. 等 20 到 60 秒，观察灯码。
6. 打开托盘。
7. 如果日志出现 `UDP ack ... active=WIRELESS state=...`，纯无线已可用。

无电脑 USB 时，日志中出现下面两行是正常的：

```text
SERIAL no matching serial port
SERIAL setup skipped; using saved firmware mode.
```

## LED 行为和诊断灯码

| 灯光 | 含义 |
| --- | --- |
| 绿灯常亮 | 空闲、任务完成或任务中止 |
| 红灯常亮 | Codex 正在思考、回复或运行工具 |
| 黄灯常亮 | 等待审批、权限或用户输入 |
| 绿灯闪烁 2 秒 | 首次建立电脑连接 |
| 黄灯慢闪 | Wi-Fi 已连接，但未收到电脑 UDP/USB 心跳 |
| 红黄交替 | 没有保存 Wi-Fi 配置，需要 USB 配网 |
| 红色双闪循环 | 有 Wi-Fi 配置，但 Wi-Fi 正在重连或连接失败 |

## 手动运行 Bridge

有线：

```powershell
python Bridge\codex_light_monitor.py --serial auto --baud 115200
```

无线：

```powershell
python Bridge\codex_light_monitor.py --udp --udp-port 4210
```

AUTO：

```powershell
python Bridge\codex_light_monitor.py --serial auto --baud 115200 --udp --udp-port 4210 --firmware-mode AUTO
```

无线模式要求电脑和 ESP32 在同一局域网，路由器没有开启 AP 隔离/客户端隔离，Windows 防火墙允许 Python 使用 UDP 4210。

## 串口命令

| 命令 | 作用 |
| --- | --- |
| `GREEN` | 设置有线状态为绿色并刷新心跳 |
| `RED` | 设置有线状态为红色并刷新心跳 |
| `YELLOW` | 设置有线状态为黄色并刷新心跳 |
| `PING` | 刷新有线心跳，回复 `PONG` |
| `STATUS` | 输出模式、活动传输、Wi-Fi、IP、UDP 诊断 |
| `MODE WIRED` | 只使用 USB，并保存模式 |
| `MODE WIRELESS` | 只使用 UDP，并保存模式 |
| `MODE AUTO` | 接受 USB 和 UDP，并保存模式 |
| `WIFI_CONFIG` | 提示当前使用 USB 配网 |
| `WIFI_SET <ssid><TAB><password>` | 通过 USB 设置 Wi-Fi，连接成功后保存 |
| `CLEAR_WIFI` | 清除已保存 Wi-Fi，等待重新配网 |

## UDP 协议

Bridge 发送：

```text
CODEXLIGHT/1 GREEN
CODEXLIGHT/1 RED
CODEXLIGHT/1 YELLOW
CODEXLIGHT/1 PING
```

ESP32 回复：

```text
CODEXLIGHT/1 ACK mac=<MAC> mode=<MODE> active=<TRANSPORT> state=<STATE>
```

ESP32 也会广播发现包：

```text
CODEXLIGHT/1 HELLO mac=<MAC> mode=<MODE>
```

默认 UDP 端口是 `4210`。

## 排障

### Wi-Fi 配网失败

- 确认 USB 已连接，且 PlatformIO Monitor 或其他串口程序没有占用 COM 口。
- ESP32-C3 只支持 2.4 GHz Wi-Fi。
- 查看 `Bridge/logs/wifi_setup.out.log` 和 `Bridge/logs/wifi_setup.err.log`。
- 当前固件默认把 ESP32-C3 Wi-Fi 发射功率限制为 8.5 dBm，以提升部分开发板的连接稳定性。

### 纯无线没有响应

- 黄灯慢闪表示 Wi-Fi 已连接，只是在等托盘 UDP；打开托盘即可。
- 红色双闪表示 Wi-Fi 正在重连或失败，检查路由器、SSID、密码和 2.4 GHz 网络。
- `ping 192.168.x.x` 不通且 `arp -a` 没有设备 MAC 时，设备没有在局域网在线。
- 重启托盘可让 Bridge 重新发现设备 IP。
- Windows 防火墙需要允许 Python UDP 4210。

### 恢复出厂状态

```powershell
cd Firmware
pio run -t erase --upload-port COM4
pio run -t upload --upload-port COM4
```

## 开发验证

```powershell
python -B -m py_compile Bridge\codex_light_monitor.py
powershell -NoProfile -Command "$e=$null; [System.Management.Automation.PSParser]::Tokenize((Get-Content -LiteralPath 'Bridge\CodexLightTray.ps1' -Raw), [ref]$e) | Out-Null; if($e){$e; exit 1}else{'OK'}"
cd Firmware
pio run
```

更多架构说明见 [Docs/使用与实现说明.md](Docs/使用与实现说明.md)。

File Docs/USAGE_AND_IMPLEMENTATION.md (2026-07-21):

# CodexLight Usage and Implementation Guide

English | [简体中文](使用与实现说明.md) | [Documentation Index](README.md) | [Project Home](../README.en.md)

This document combines the operating guide and technical implementation reference for firmware flashing, USB Wi-Fi provisioning, wired/wireless operation, troubleshooting, and maintenance.

## Hardware Connections

| LED | Data pin | State |
| --- | --- | --- |
| Yellow WS2812B | GPIO5 | Disconnected, waiting, or diagnostics |
| Green WS2812B | GPIO6 | Connection animation or task completed |
| Red WS2812B | GPIO7 | Codex is working or Wi-Fi reconnect diagnostics |

Each WS2812B uses an independent DIN. Connect VCC to a stable 5 V supply and share ground with the ESP32-C3.

## Build and Upload

```powershell
cd C:\path\to\CodexLight\Firmware
pio run
pio run -t upload --upload-port COM4
pio device monitor --port COM4 --baud 115200
```

Close PlatformIO Monitor before starting the Bridge because both use the same serial port.

## USB Wi-Fi Provisioning

The current firmware does not open a SoftAP provisioning portal. Provisioning is done over USB serial.

Tray workflow:

1. Connect the device over USB.
2. Start `Bridge\start_codex_light_tray.vbs`, which defaults to `WIRELESS` mode.
3. Right-click the tray icon and choose `Configure WiFi`.
4. Enter SSID/password and save.

Command-line workflow:

```powershell
python Bridge\codex_light_monitor.py --serial auto --wifi-ssid "YourWifi" --wifi-password "YourPassword"
```

Firmware command:

```text
WIFI_SET <ssid><TAB><password>
```

Credentials are saved only after `WiFi.status() == WL_CONNECTED`. Failed attempts are not persisted.

## Transport Modes

| Mode | Behavior |
| --- | --- |
| `WIRED` | USB serial heartbeat only |
| `WIRELESS` | UDP heartbeat only |
| `AUTO` | USB and UDP accepted; USB heartbeat has priority when fresh |

Mode commands:

```text
MODE WIRED
MODE WIRELESS
MODE AUTO
STATUS
```

The mode is stored under Preferences namespace `codexlight`, key `transport`.

## Windows Tray

Use the hidden launcher, which defaults to `WIRELESS` mode:

```text
Bridge\start_codex_light_tray.vbs
```

The tray hosts these user actions:

- `Configure WiFi`: USB provisioning.
- `Connection mode`: switches between AUTO, WIRED, and WIRELESS.
- `Open log folder`: opens `Bridge/logs`.
- `Restart monitor`: restarts `codex_light_monitor.py`.
- `Exit`: stops the tray app.

The wireless tray path opens serial only for setup when USB exists, sends a reset pulse and `MODE WIRELESS`, then releases the port. If no USB serial port exists, it logs `SERIAL setup skipped; using saved firmware mode.` and continues over UDP.

## Architecture

```text
Codex Desktop logs
        |
        v
Bridge/codex_light_monitor.py
        |
        +-- USB CDC serial: GREEN / RED / YELLOW / MODE / WIFI_SET
        +-- LAN UDP: CODEXLIGHT/1 <STATE> and CODEXLIGHT/1 PING
                         |
                         v
                  ESP32-C3 firmware
                         |
                         +-- Preferences: wifi ssid/password, transport mode
                         +-- non-blocking saved Wi-Fi reconnect
                         +-- GPIO5 yellow WS2812B
                         +-- GPIO6 green WS2812B
                         +-- GPIO7 red WS2812B
```

## Bridge Implementation

The Bridge reads:

- `~/.codex/sessions/**/*.jsonl`
- `~/.codex/logs_2.sqlite`

It sends only state colors to the device.

| Codex event | Output |
| --- | --- |
| `task_started`, messages, reasoning, tool calls, tool outputs | `RED` |
| Approval, permission, or explicit user input needed | `YELLOW` |
| `task_complete` or `turn_aborted` | `GREEN` |

The tray Wi-Fi setup path pauses the monitor, runs a one-shot `--wifi-config` child process, writes logs to `Bridge/logs/wifi_setup.*.log`, then restarts the monitor.

## Firmware Implementation

Main files:

- `Firmware/src/main.cpp`: serial command parser, UDP heartbeat, transport selection, LED state machine, diagnostics.
- `Firmware/src/config_portal.cpp`: STA Wi-Fi connection, USB provisioning wrapper, non-blocking saved Wi-Fi reconnect.
- `Firmware/src/storage.cpp`: Preferences storage for Wi-Fi credentials.
- `Firmware/src/led.cpp`: three independent NeoPixel outputs.
- `Firmware/include/config.h`: GPIO, brightness, timeouts, UDP port, default mode, and ESP32-C3 Wi-Fi transmit power.

Wi-Fi notes:

- USB serial is the only provisioning method.
- Credentials are stored only after the STA interface reaches `WL_CONNECTED`.
- Saved Wi-Fi starts non-blockingly at boot, so LED diagnostics and the main loop continue even when the AP is unavailable.
- Failed saved Wi-Fi connections keep credentials and retry every 10 seconds.
- ESP32-C3 transmit power is limited to `WIFI_MAX_TX_POWER_QDBM = 34` (8.5 dBm) to improve wireless stability on compact development boards.
- Default debug serial output is disabled for standalone wireless operation.

Startup flow:

```text
setup
  -> initialize LEDs and show startup yellow
  -> read saved Wi-Fi credentials
  -> if present, start STA connection without blocking the main loop
  -> load persisted transport mode
loop
  -> continue saved Wi-Fi reconnect attempts when needed
  -> handle USB serial commands when available
  -> maintain UDP when Wi-Fi is connected
  -> select active transport
  -> render LED state or standalone diagnostics
```

## Protocol

Serial commands:

```text
GREEN
RED
YELLOW
PING
STATUS
MODE WIRED
MODE WIRELESS
MODE AUTO
WIFI_CONFIG
WIFI_SET <ssid><TAB><password>
CLEAR_WIFI
LED_TEST RED
LED_TEST GREEN
LED_TEST YELLOW
LED_TEST OFF
```

UDP states, pings, ACKs, and discovery:

```text
CODEXLIGHT/1 GREEN
CODEXLIGHT/1 RED
CODEXLIGHT/1 YELLOW
CODEXLIGHT/1 PING
CODEXLIGHT/1 ACK mac=<MAC> mode=<MODE> active=<TRANSPORT> state=<STATE>
CODEXLIGHT/1 HELLO mac=<MAC> mode=<MODE>
```

## Troubleshooting

- Wi-Fi setup fails: check `Bridge/logs/wifi_setup.out.log` and `.err.log`, close PlatformIO Monitor, verify 2.4 GHz Wi-Fi, and confirm firmware uses `WIFI_MAX_TX_POWER_QDBM = 34`.
- Wireless does not update: confirm same LAN, allow UDP 4210 through firewall, and restart the tray to rediscover the device.
- Slow yellow blink: Wi-Fi is connected and the firmware is waiting for desktop heartbeats; start the tray.
- Red double-blink: saved Wi-Fi exists but connection is still failing or reconnecting.
- Colors are wrong: verify `NEO_GRB`, DIN orientation, GPIO continuity, and 5 V power.

## Security

- Wi-Fi credentials are stored in ESP32 NVS and are not printed over serial.
- UDP is unauthenticated and unencrypted; use only on trusted LANs.

## Verification

```powershell
python -B -m py_compile Bridge\codex_light_monitor.py
cd Firmware
pio run
```

## License

The project is distributed under the repository [MIT License](../LICENSE).

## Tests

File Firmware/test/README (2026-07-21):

# Firmware Tests

This directory is reserved for PlatformIO unit and hardware-in-the-loop tests.

本目录预留给 PlatformIO 单元测试和硬件在环测试。

There are currently no automated firmware tests. Before submitting firmware changes, run at least:

当前没有自动化固件测试。提交固件修改前至少执行：

```powershell
cd Firmware
pio run
```

Hardware validation should cover:

- USB serial commands: `STATUS`, `MODE ...`, `WIFI_SET`, `CLEAR_WIFI`, `LED_TEST ...`.
- STA Wi-Fi connection after USB provisioning.
- Non-blocking saved Wi-Fi startup without a serial monitor attached.
- Power bank or battery-powered wireless operation.
- UDP discovery, ACKs, and heartbeat timeout.
- AUTO/WIRED/WIRELESS mode switching.
- Two-second green connection animation.
- Standalone LED diagnostics: alternating red/yellow, red double-blink, slow yellow blink.
- Exclusive red/green/yellow LED output.

硬件验证应覆盖 USB 串口命令、USB 配网后的 STA 联网、无串口的非阻塞启动、充电宝或电池供电的纯无线运行、UDP 发现和 ACK、三种模式切换、绿灯连接动画、无串口诊断灯码，以及红/绿/黄三灯互斥显示。

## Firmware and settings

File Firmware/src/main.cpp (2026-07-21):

#include <Arduino.h>
#include <Preferences.h>
#include <WiFi.h>
#include <WiFiUdp.h>

#include "config.h"
#include "config_portal.h"
#include "led.h"

namespace {

using namespace CodexLightConfig;

enum class TransportMode {
  Auto,
  Wired,
  Wireless,
};

enum class Transport {
  None,
  Wired,
  Wireless,
};

enum class LightState {
  Green,
  Red,
  Yellow,
};

enum class LedFrame {
  Off,
  Green,
  Red,
  Yellow,
};

LedController leds;
ConfigPortal configPortal;
Preferences preferences;
WiFiUDP udp;

TransportMode transportMode = TransportMode::Auto;
Transport activeTransport = Transport::None;
LightState wiredState = LightState::Green;
LightState wirelessState = LightState::Green;

String serialBuffer;
bool udpStarted = false;
unsigned long lastWiredPacketMs = 0;
unsigned long lastWirelessPacketMs = 0;
unsigned long lastHelloMs = 0;
unsigned long lastUdpPacketMs = 0;
unsigned long udpPacketCount = 0;
String lastUdpText;
bool linkWasConnected = false;
bool connectionAnimationActive = false;
unsigned long connectionAnimationStartedMs = 0;
LedFrame displayedFrame = LedFrame::Off;
unsigned long lastLedRefreshMs = 0;
bool ledsInitialized = false;

void debugPrint(const String& message) {
  if (!DEBUG_SERIAL) {
    return;
  }
  Serial.print("[CodexLight ");
  Serial.print(millis());
  Serial.print(" ms] ");
  Serial.println(message);
}

const char* modeName(TransportMode mode) {
  switch (mode) {
    case TransportMode::Auto:
      return "AUTO";
    case TransportMode::Wired:
      return "WIRED";
    case TransportMode::Wireless:
      return "WIRELESS";
  }
  return "AUTO";
}

const char* transportName(Transport transport) {
  switch (transport) {
    case Transport::Wired:
      return "WIRED";
    case Transport::Wireless:
      return "WIRELESS";
    case Transport::None:
      return "NONE";
  }
  return "NONE";
}

const char* stateName(LightState state) {
  switch (state) {
    case LightState::Green:
      return "GREEN";
    case LightState::Red:
      return "RED";
    case LightState::Yellow:
      return "YELLOW";
  }
  return "GREEN";
}

TransportMode parseMode(String value) {
  value.trim();
  value.toUpperCase();
  if (value == "WIRED") {
    return TransportMode::Wired;
  }
  if (value == "WIRELESS") {
    return TransportMode::Wireless;
  }
  return TransportMode::Auto;
}

bool parseState(String command, LightState& state) {
  command.trim();
  command.toUpperCase();
  if (command.endsWith(" GREEN")) {
    command = "GREEN";
  } else if (command.endsWith(" RED")) {
    command = "RED";
  } else if (command.endsWith(" YELLOW")) {
    command = "YELLOW";
  }

  if (command == "GREEN") {
    state = LightState::Green;
    return true;
  }
  if (command == "RED") {
    state = LightState::Red;
    return true;
  }
  if (command == "YELLOW") {
    state = LightState::Yellow;
    return true;
  }
  return false;
}

void showFrame(LedFrame frame, unsigned long now) {
  const bool frameChanged = frame != displayedFrame;
  const bool refreshDue = now - lastLedRefreshMs >= LED_REFRESH_INTERVAL_MS;
  if (!frameChanged && !refreshDue) {
    return;
  }

  switch (frame) {
    case LedFrame::Off:
      leds.allOff();
      break;
    case LedFrame::Green:
      leds.showGreen();
      break;
    case LedFrame::Red:
      leds.showRed();
      break;
    case LedFrame::Yellow:
      leds.showYellow();
      break;
  }
  displayedFrame = frame;
  lastLedRefreshMs = now;
}

void showState(LightState state, unsigned long now) {
  switch (state) {
    case LightState::Green:
      showFrame(LedFrame::Green, now);
      break;
    case LightState::Red:
      showFrame(LedFrame::Red, now);
      break;
    case LightState::Yellow:
      showFrame(LedFrame::Yellow, now);
      break;
  }
}

bool packetIsFresh(unsigned long packetMs, unsigned long now) {
  return packetMs != 0 && now - packetMs <= LINK_TIMEOUT_MS;
}

Transport selectActiveTransport(unsigned long now) {
  const bool wiredFresh = packetIsFresh(lastWiredPacketMs, now);
  const bool wirelessFresh = packetIsFresh(lastWirelessPacketMs, now);

  if (transportMode == TransportMode::Wired) {
    return wiredFresh ? Transport::Wired : Transport::None;
  }
  if (transportMode == TransportMode::Wireless) {
    return wirelessFresh ? Transport::Wireless : Transport::None;
  }
  if (wiredFresh) {
    return Transport::Wired;
  }
  if (wirelessFresh) {
    return Transport::Wireless;
  }
  return Transport::None;
}

void saveMode() {
  preferences.begin("codexlight", false);
  preferences.putString("transport", modeName(transportMode));
  preferences.end();
}

void saveMode(TransportMode mode) {
  transportMode = mode;
  saveMode();
  lastWiredPacketMs = 0;
  lastWirelessPacketMs = 0;
}

void loadMode() {
  preferences.begin("codexlight", false);
  const String saved = preferences.getString("transport", DEFAULT_TRANSPORT_MODE);
  preferences.end();
  transportMode = parseMode(saved);
}

void printStatus() {
  Serial.print("STATUS mode=");
  Serial.print(modeName(transportMode));
  Serial.print(" active=");
  Serial.print(transportName(activeTransport));
  Serial.print(" wifi=");
  Serial.print(configPortal.wifiConnected() ? "CONNECTED" : "DISCONNECTED");
  Serial.print(" sta_status=");
  Serial.print(configPortal.wifiStatusName());
  Serial.print(" target_ssid=");
  if (configPortal.configuredSsid().length() > 0) {
    Serial.print(configPortal.configuredSsid());
  } else {
    Serial.print("NONE");
  }
  Serial.print(" disconnect_reason=");
  Serial.print(configPortal.lastDisconnectReason());
  Serial.print(" network=");
  Serial.print(configPortal.stateName());
  Serial.print(" radio=");
  switch (WiFi.getMode()) {
    case WIFI_MODE_NULL:
      Serial.print("OFF");
      break;
    case WIFI_MODE_STA:
      Serial.print("STA");
      break;
    case WIFI_MODE_AP:
      Serial.print("AP");
      break;
    case WIFI_MODE_APSTA:
      Serial.print("AP_STA");
      break;
    default:
      Serial.print("UNKNOWN");
      break;
  }
  if (configPortal.portalActive()) {
    Serial.print(" ap=");
    Serial.print(WiFi.softAPSSID());
    Serial.print(" ap_ip=");
    Serial.print(WiFi.softAPIP());
    Serial.print(" ap_clients=");
    Serial.print(WiFi.softAPgetStationNum());
  }
  if (configPortal.wifiConnected()) {
    Serial.print(" ip=");
    Serial.print(WiFi.localIP());
  }
  Serial.print(" udp_packets=");
  Serial.print(udpPacketCount);
  Serial.print(" last_udp_ms=");
  Serial.print(lastUdpPacketMs);
  if (lastUdpText.length() > 0) {
    Serial.print(" last_udp=");
    Serial.print(lastUdpText);
  }
  Serial.println();
}

void handleControlCommand(String command) {
  command.trim();
  String upper = command;
  upper.toUpperCase();

  if (upper.startsWith("MODE ")) {
    saveMode(parseMode(upper.substring(5)));
    Serial.println(String("MODE_OK ") + modeName(transportMode));
    return;
  }
  if (upper == "STATUS") {
    printStatus();
    return;
  }
  if (upper == "WIFI_CONFIG") {
    Serial.println("WIFI_USB_PROVISIONING READY FORMAT=WIFI_SET <ssid><TAB><password>");
    return;
  }
  if (upper == "CLEAR_WIFI") {
    configPortal.resetSettings();
    Serial.println("WIFI_CLEARED USB_PROVISIONING");
    return;
  }
  if (upper.startsWith("WIFI_SET ")) {
    const int separator = command.indexOf('\t', 9);
    if (separator < 0) {
      Serial.println("WIFI_SET_ERROR FORMAT");
      return;
    }
    String ssid = command.substring(9, separator);
    const String password = command.substring(separator + 1);
    ssid.trim();
    if (ssid.length() == 0 || ssid.length() > 32 || password.length() > 64 ||
        (password.length() > 0 && password.length() < 8)) {
      Serial.println("WIFI_SET_ERROR INVALID_CREDENTIALS");
      return;
    }
    configPortal.configure(ssid, password);
    if (configPortal.wifiConnected()) {
      saveMode(TransportMode::Wireless);
      Serial.println(String("WIFI_SET_OK ") + ssid + " " + WiFi.localIP().toString());
    } else {
      Serial.println(String("WIFI_SET_ERROR CONNECT_FAILED ") + ssid);
    }
    return;
  }
  if (upper == "LED_TEST RED") {
    showFrame(LedFrame::Red, millis());
    Serial.println("LED_TEST_OK RED");
    return;
  }
  if (upper == "LED_TEST GREEN") {
    showFrame(LedFrame::Green, millis());
    Serial.println("LED_TEST_OK GREEN");
    return;
  }
  if (upper == "LED_TEST YELLOW") {
    showFrame(LedFrame::Yellow, millis());
    Serial.println("LED_TEST_OK YELLOW");
    return;
  }
  if (upper == "LED_TEST OFF") {
    showFrame(LedFrame::Off, millis());
    Serial.println("LED_TEST_OK OFF");
    return;
  }
  LightState state;
  if (upper == "PING") {
    lastWiredPacketMs = millis();
    Serial.println("PONG");
    return;
  }
  if (parseState(upper, state)) {
    wiredState = state;
    lastWiredPacketMs = millis();
    Serial.println(String("STATE_OK ") + stateName(state));
  }
}

void handleSerialInput() {
  while (Serial.available() > 0) {
    const char ch = static_cast<char>(Serial.read());
    if (ch == '\n' || ch == '\r') {
      if (serialBuffer.length() > 0) {
        handleControlCommand(serialBuffer);
        serialBuffer = "";
      }
      continue;
    }
    if (serialBuffer.length() < 128) {
      serialBuffer += ch;
    } else {
      serialBuffer = "";
    }
  }
}

void sendHello() {
  if (!udpStarted) {
    return;
  }
  const String message = "CODEXLIGHT/1 HELLO mac=" + WiFi.macAddress() +
                         " mode=" + modeName(transportMode);
  udp.beginPacket(IPAddress(255, 255, 255, 255), UDP_PORT);
  udp.print(message);
  udp.endPacket();
}

void sendUdpAck(IPAddress remoteIp, uint16_t remotePort) {
  if (!udpStarted) {
    return;
  }
  const String message = "CODEXLIGHT/1 ACK mac=" + WiFi.macAddress() +
                         " mode=" + modeName(transportMode) +
                         " active=" + transportName(activeTransport) +
                         " state=" + stateName(activeTransport == Transport::Wired ? wiredState : wirelessState);
  udp.beginPacket(remoteIp, remotePort);
  udp.print(message);
  udp.endPacket();
}

void maintainUdp() {
  if (!configPortal.wifiConnected()) {
    if (udpStarted) {
      udp.stop();
      udpStarted = false;
    }
    return;
  }

  if (!udpStarted) {
    udpStarted = udp.begin(UDP_PORT) == 1;
    if (udpStarted) {
      debugPrint("UDP listening on " + String(UDP_PORT) + " at " + WiFi.localIP().toString());
      sendHello();
    }
  }

  if (!udpStarted) {
    return;
  }

  const unsigned long now = millis();
  if (now - lastHelloMs >= 2000UL) {
    lastHelloMs = now;
    sendHello();
  }

  const int packetSize = udp.parsePacket();
  if (packetSize <= 0) {
    return;
  }

  const IPAddress remoteIp = udp.remoteIP();
  const uint16_t remotePort = udp.remotePort();

  char packet[128];
  const int length = udp.read(packet, sizeof(packet) - 1);
  if (length <= 0) {
    return;
  }
  packet[length] = '\0';

  String command(packet);
  lastUdpPacketMs = now;
  udpPacketCount += 1;
  lastUdpText = command;
  lastUdpText.trim();
  LightState state;
  String upper = command;
  upper.trim();
  upper.toUpperCase();
  if (upper == "PING" || upper == "CODEXLIGHT/1 PING") {
    lastWirelessPacketMs = now;
    activeTransport = selectActiveTransport(now);
    sendUdpAck(remoteIp, remotePort);
  } else if (parseState(upper, state)) {
    wirelessState = state;
    lastWirelessPacketMs = now;
    activeTransport = selectActiveTransport(now);
    sendUdpAck(remoteIp, remotePort);
  }
}

void updateLeds() {
  if (!ledsInitialized) {
    return;
  }

  const unsigned long now = millis();
  activeTransport = selectActiveTransport(now);
  const bool connected = activeTransport != Transport::None;

  if (connected && !linkWasConnected) {
    connectionAnimationActive = true;
    connectionAnimationStartedMs = now;
    debugPrint(String("Computer link connected via ") + transportName(activeTransport));
  } else if (!connected && linkWasConnected) {
    connectionAnimationActive = false;
    debugPrint("Computer link disconnected");
  }
  linkWasConnected = connected;

  if (!connected) {
    const bool on = (now / DISCONNECTED_BLINK_HALF_PERIOD_MS) % 2 == 0;
    if (on) {
      showFrame(LedFrame::Yellow, now);
    } else {
      showFrame(LedFrame::Off, now);
    }
    return;
  }

  if (connectionAnimationActive) {
    if (now - connectionAnimationStartedMs < CONNECTED_ANIMATION_MS) {
      const bool on = ((now - connectionAnimationStartedMs) /
                       CONNECTED_BLINK_HALF_PERIOD_MS) % 2 == 0;
      if (on) {
        showFrame(LedFrame::Green, now);
      } else {
        showFrame(LedFrame::Off, now);
      }
      return;
    }
    connectionAnimationActive = false;
  }

  showState(activeTransport == Transport::Wired ? wiredState : wirelessState, now);
}

void maintainLedController() {
  if (ledsInitialized) {
    return;
  }

  leds.begin();
  ledsInitialized = true;
  displayedFrame = LedFrame::Off;
  lastLedRefreshMs = 0;
  debugPrint("LED controller enabled after Wi-Fi provisioning");
}

}  // namespace

void setup() {
  Serial.begin(SERIAL_BAUD);
  delay(500);
  Serial.println();
  Serial.println("CODEXLIGHT READY");

  maintainLedController();
  showFrame(LedFrame::Yellow, millis());

  configPortal.begin();
  Serial.println("WIFI_PROVISIONING USB_SERIAL");
  Serial.flush();
  configPortal.autoConnect();
  if (configPortal.wifiConnected()) {
    Serial.println(String("WIFI_CONNECTED ") + WiFi.SSID() + " " + WiFi.localIP().toString());
    maintainUdp();
  } else {
    Serial.println("WIFI_USB_PROVISIONING READY FORMAT=WIFI_SET <ssid><TAB><password>");
  }

  loadMode();
  debugPrint(String("Boot mode=") + modeName(transportMode));
  debugPrint(String("Config AP=") + configPortal.apSsid());
  printStatus();
}

void loop() {
  configPortal.loop();
  handleSerialInput();
  maintainLedController();
  maintainUdp();
  updateLeds();
  delay(2);
}

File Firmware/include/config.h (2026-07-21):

#ifndef CODEXLIGHT_CONFIG_H
#define CODEXLIGHT_CONFIG_H

#include <Arduino.h>

namespace CodexLightConfig {

constexpr uint8_t RED_LED_PIN = 7;
constexpr uint8_t GREEN_LED_PIN = 6;
constexpr uint8_t YELLOW_LED_PIN = 5;

constexpr uint8_t LEDS_PER_CHANNEL = 1;
constexpr uint8_t DEFAULT_BRIGHTNESS = 50;

constexpr unsigned long SERIAL_BAUD = 115200;
constexpr uint16_t UDP_PORT = 4210;
constexpr unsigned long LINK_TIMEOUT_MS = 6000;
constexpr unsigned long WIFI_CONNECT_TIMEOUT_MS = 15000;
constexpr unsigned long WIFI_RECONNECT_INTERVAL_MS = 10000;
// ESP-IDF uses quarter-dBm units here. 34 means 8.5 dBm, which is more stable
// on some ESP32-C3 Super Mini boards whose PCB antenna distorts at full power.
constexpr int8_t WIFI_MAX_TX_POWER_QDBM = 34;
constexpr unsigned long DISCONNECTED_BLINK_HALF_PERIOD_MS = 500;
constexpr unsigned long CONNECTED_ANIMATION_MS = 2000;
constexpr unsigned long CONNECTED_BLINK_HALF_PERIOD_MS = 250;
constexpr unsigned long LED_REFRESH_INTERVAL_MS = 1000;

// AP provisioning hotspot settings.
constexpr const char* CONFIG_AP_SSID_PREFIX = "CodexLight_Setup";
constexpr const char* CONFIG_AP_PASSWORD = "12345678";
constexpr int32_t CONFIG_AP_CHANNEL = 6;
constexpr uint8_t CONFIG_AP_MAX_CLIENTS = 4;

// Change this to "WIRED" or "WIRELESS" to choose a fixed startup mode.
// "AUTO" accepts both transports and prefers a recent wired heartbeat.
constexpr const char* DEFAULT_TRANSPORT_MODE = "AUTO";

// Enables firmware diagnostics on the USB serial port. Open the VS Code /
// PlatformIO serial monitor at SERIAL_BAUD to inspect transport, Wi-Fi, UDP,
// configuration portal, and MAC status while debugging hardware setup.
constexpr bool DEBUG_SERIAL = false;

constexpr uint8_t RED_COLOR_R = 255;
constexpr uint8_t RED_COLOR_G = 0;
constexpr uint8_t RED_COLOR_B = 0;

constexpr uint8_t GREEN_COLOR_R = 0;
constexpr uint8_t GREEN_COLOR_G = 255;
constexpr uint8_t GREEN_COLOR_B = 0;

constexpr uint8_t YELLOW_COLOR_R = 255;
constexpr uint8_t YELLOW_COLOR_G = 255;
constexpr uint8_t YELLOW_COLOR_B = 0;

}  // namespace CodexLightConfig

#endif  // CODEXLIGHT_CONFIG_H

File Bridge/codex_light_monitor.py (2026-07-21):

#!/usr/bin/env python3
"""Monitor local Codex logs and emit CodexLight states.

States:
  GREEN  - idle, completed, or no recent agent activity
  RED    - Codex is thinking, writing, or running tools
  YELLOW - Codex is waiting for approval or explicit user input

The script uses only Python's standard library by default. If --serial is used,
pyserial must be installed in the Python environment running this script.
"""

from __future__ import annotations

import argparse
import json
import re
import socket
import sqlite3
import time
from dataclasses import dataclass, field
from pathlib import Path
from typing import Dict, Iterable, Optional


STATE_GREEN = "GREEN"
STATE_RED = "RED"
STATE_YELLOW = "YELLOW"
DEFAULT_CONFIG_PATH = Path(__file__).with_name("config.local.json")
SERIAL_READY_DELAY_SECONDS = 2.0
SERIAL_MODE_RETRY_SECONDS = 1.0
SERIAL_RESET_DELAY_SECONDS = 0.15


@dataclass
class MonitorState:
    state: str = STATE_GREEN
    reason: str = "startup"
    last_activity: float = field(default_factory=time.monotonic)
    last_emit: float = 0.0
    pending_calls: Dict[str, str] = field(default_factory=dict)
    pending_approvals: Dict[str, str] = field(default_factory=dict)
    active_turn_id: Optional[str] = None
    completion_latched: bool = False


class StateEmitter:
    def __init__(
        self,
        serial_port: Optional[str],
        baud: int,
        repeat: bool,
        udp: bool,
        udp_host: str,
        udp_port: int,
        udp_interval: float,
        device_mac: str,
        device_ip: str,
        config_path: Path,
        config: dict,
        firmware_mode: str = "",
        serial_setup_only: bool = False,
        mode_setup_enabled: bool = True,
        reset_on_connect: bool = False,
    ) -> None:
        self.repeat = repeat
        self.last_state: Optional[str] = None
        self.serial_port = serial_port
        self.baud = baud
        self.serial = None
        self.serial_module = None
        self.list_ports_module = None
        self.last_connect_attempt = 0.0
        self.udp_enabled = udp
        self.udp_host = udp_host
        self.udp_port = udp_port
        self.udp_interval = udp_interval
        self.device_mac = normalize_mac(device_mac)
        self.device_ip = device_ip
        self.config_path = config_path
        self.config = config
        self.udp_socket = None
        self.last_udp_send = 0.0
        self.last_udp_broadcast_send = 0.0
        self.last_udp_subnet_probe = 0.0
        self.last_serial_send = 0.0
        self.last_udp_listen = 0.0
        self.serial_mode = firmware_mode or ("AUTO" if self.udp_enabled else "WIRED")
        self.serial_setup_only = serial_setup_only
        self.serial_setup_complete = False
        self.serial_mode_confirmed = False
        self.last_serial_mode_send = 0.0
        self.last_serial_status_send = 0.0
        self.mode_setup_enabled = mode_setup_enabled
        self.reset_on_connect = reset_on_connect

        if serial_port:
            try:
                import serial  # type: ignore
                from serial.tools import list_ports  # type: ignore
            except ImportError as exc:
                if self.serial_setup_only and self.udp_enabled:
                    print(
                        f"{time.strftime('%Y-%m-%d %H:%M:%S')} "
                        "SERIAL setup unavailable; using saved firmware mode.",
                        flush=True,
                    )
                    self.serial_port = None
                else:
                    raise SystemExit(
                        "pyserial is required for --serial. Install it with: pip install pyserial"
                    ) from exc
            else:
                self.serial_module = serial
                self.list_ports_module = list_ports
            self.connect_serial(force=True)

        if self.udp_enabled:
            self.udp_socket = socket.socket(socket.AF_INET, socket.SOCK_DGRAM)
            self.udp_socket.setsockopt(socket.SOL_SOCKET, socket.SO_BROADCAST, 1)
            self.udp_socket.setsockopt(socket.SOL_SOCKET, socket.SO_REUSEADDR, 1)
            self.udp_socket.setblocking(False)
            try:
                self.udp_socket.bind(("", self.udp_port))
            except OSError as exc:
                print(f"{time.strftime('%Y-%m-%d %H:%M:%S')} UDP listen disabled: {exc}", flush=True)

    def configure_wifi(self, ssid: str, password: str, timeout: float = 45.0) -> bool:
        if not ssid or len(ssid) > 32 or len(password) > 64 or (password and len(password) < 8):
            print("WIFI_SETUP_ERROR INVALID_CREDENTIALS", flush=True)
            return False

        deadline = time.monotonic() + timeout
        while time.monotonic() < deadline:
            self.connect_serial(force=self.serial is None)
            if self.serial is not None:
                break
            time.sleep(0.5)

        if self.serial is None:
            print("WIFI_SETUP_ERROR SERIAL_NOT_FOUND", flush=True)
            return False

        try:
            self.serial.reset_input_buffer()
            self.serial.write(f"WIFI_SET {ssid}\t{password}\n".encode("utf-8"))
            self.serial.flush()
        except Exception as exc:
            print(f"WIFI_SETUP_ERROR SERIAL_WRITE_FAILED {exc}", flush=True)
            self.close_serial()
            return False

        while time.monotonic() < deadline:
            try:
                line = self.serial.readline().decode("utf-8", errors="replace").strip()
            except Exception as exc:
                print(f"WIFI_SETUP_ERROR SERIAL_READ_FAILED {exc}", flush=True)
                self.close_serial()
                return False
            if not line:
                continue
            print(f"DEVICE {line}", flush=True)
            if line.startswith("WIFI_SET_OK "):
                parts = line.split()
                if len(parts) >= 3:
                    self.device_ip = parts[-1]
                    self.config["last_device_ip"] = self.device_ip
                    save_local_config(self.config_path, self.config)
                return True
            if line.startswith("WIFI_SET_ERROR "):
                return False

        print("WIFI_SETUP_ERROR TIMEOUT", flush=True)
        return False

    def connect_serial(self, force: bool = False) -> None:
        if not self.serial_port or self.serial_module is None:
            return
        if self.serial_setup_only and self.serial_setup_complete:
            return

        now = time.monotonic()
        if not force and now - self.last_connect_attempt < 5.0:
            return
        self.last_connect_attempt = now

        if self.serial is not None and getattr(self.serial, "is_open", False):
            return
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

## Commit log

2026-07-14 feat: add UDP wireless bridge support
2026-07-15 feat: add paired UDP device binding
    [codex_light_monitor.py, main.cpp]
2026-07-16 docs(hardware): add 3D printable enclosure files
2026-07-16 docs(hardware): update PCB source project
2026-07-17 fix: correct LED colors and update project documentation
    [codex_light_monitor.py, config.h, led.cpp]
2026-07-17 chore(hardware): update bottom enclosure model
    [CodexLight_B.stl]
2026-07-17 docs(hardware): add BOM and refresh project documentation
    [BOM.xlsx]
2026-07-17 docs(hardware): update bill of materials
    [BOM.xlsx]
2026-07-21 fix: stabilize tray wifi setup
    [codex_light_monitor.py]
2026-07-21 fix: lower esp32c3 wifi transmit power
    [config.h]
2026-07-21 docs: document esp32c3 wifi power workaround
2026-07-21 fix: initialize leds before wifi startup
    [main.cpp]
2026-07-21 fix: keep wireless mode active without usb
    [codex_light_monitor.py, main.cpp]
2026-07-21 fix: send udp across network changes
    [codex_light_monitor.py]
2026-07-21 fix: listen for wireless udp acknowledgements
    [codex_light_monitor.py]
2026-07-21 fix: update wireless state before ack
    [main.cpp]
2026-07-21 fix: start udp before bridge heartbeats
    [codex_light_monitor.py, main.cpp]
2026-07-21 chore: reduce wireless diagnostic noise
    [codex_light_monitor.py]
2026-07-21 fix: preserve saved wifi during reconnect
    [config.h]
2026-07-21 fix: reset device during wireless tray startup
    [codex_light_monitor.py, main.cpp]
2026-07-21 docs: update wireless setup and usage guides
